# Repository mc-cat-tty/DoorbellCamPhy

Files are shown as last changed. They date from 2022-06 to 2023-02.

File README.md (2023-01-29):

# DoorbellCamPhy
## Notifier PCB
[Schematic](NotifierPcb/Exports/NotifierPcbSchematic.pdf)

[Board](NotifierPcb/Exports/NotifierPcbBoard.pdf)

<p>
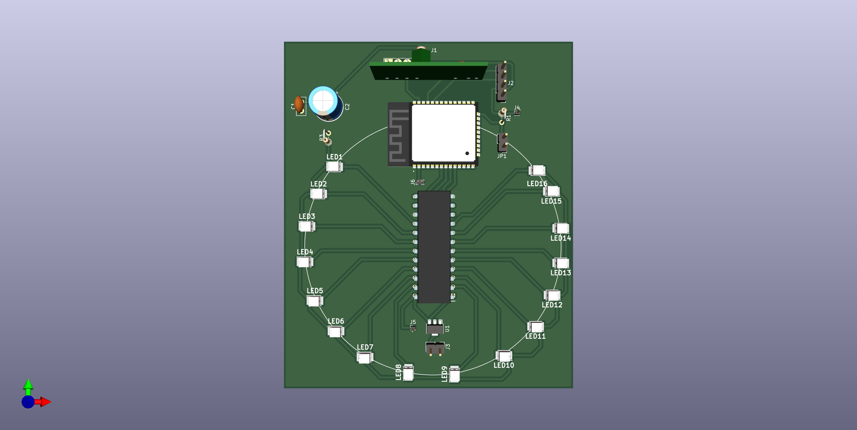
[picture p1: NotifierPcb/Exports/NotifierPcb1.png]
 
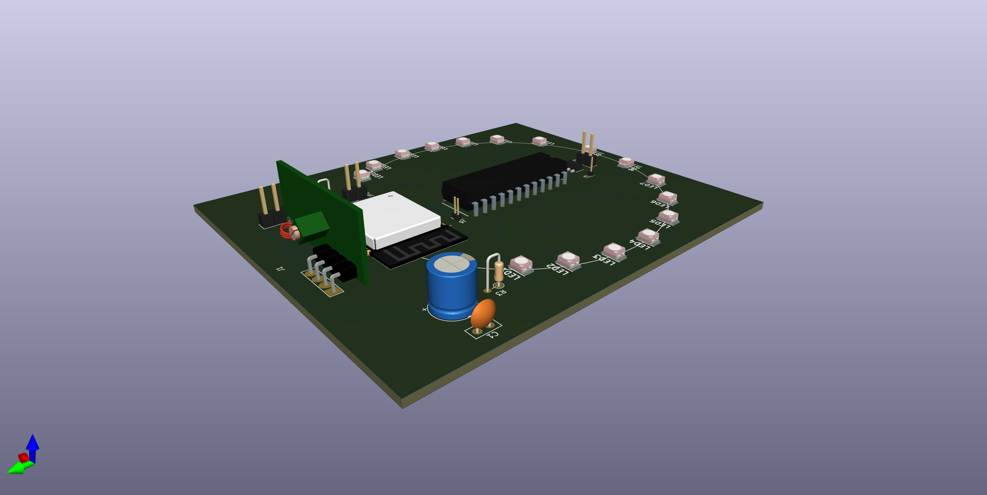
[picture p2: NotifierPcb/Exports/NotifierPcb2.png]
 
 <br>
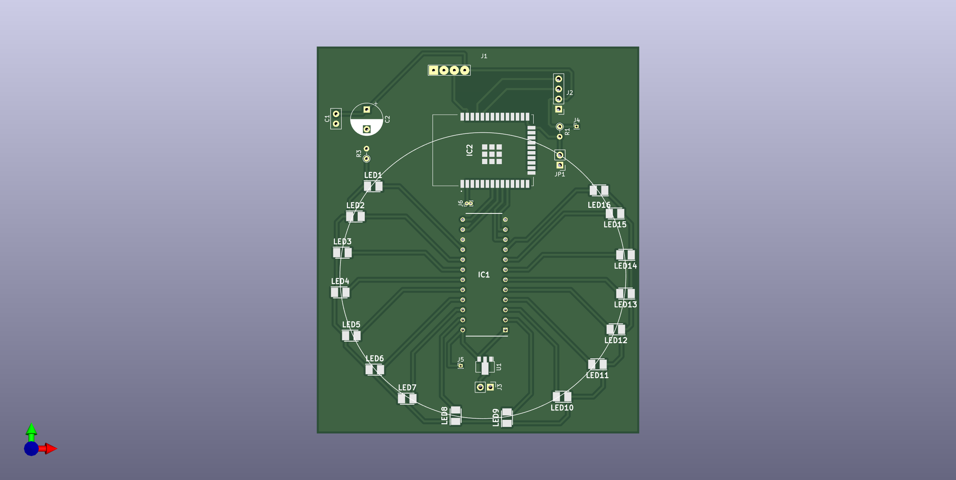
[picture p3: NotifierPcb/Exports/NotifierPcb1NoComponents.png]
 
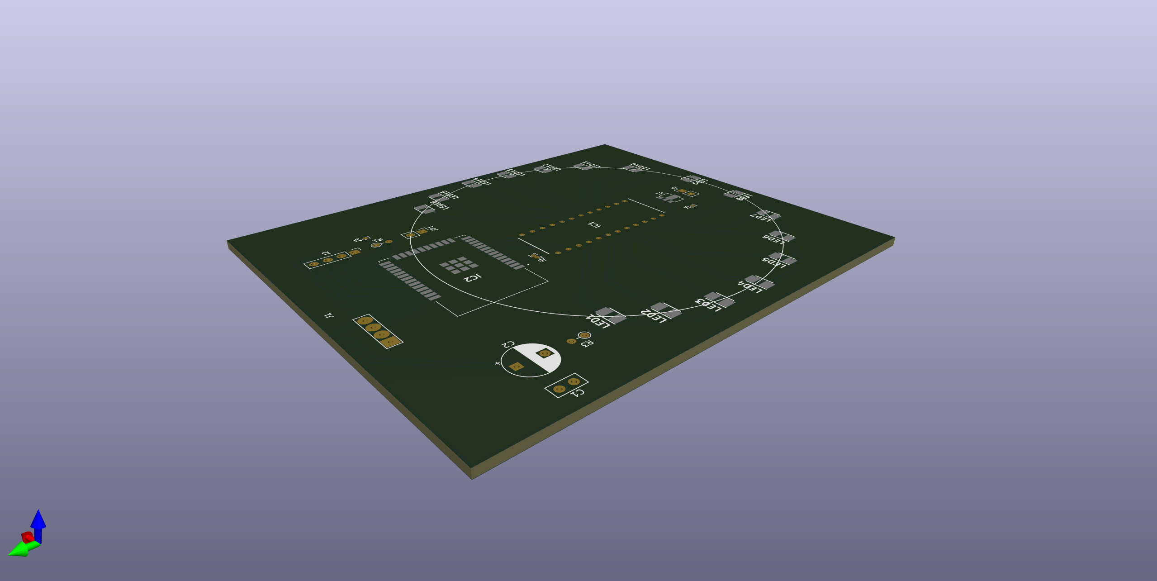
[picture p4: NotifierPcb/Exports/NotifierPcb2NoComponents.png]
 
</p>

## Notifier PCB end result


## Camera holder
[3D Model](Holder/holderv24.stl)

<p>
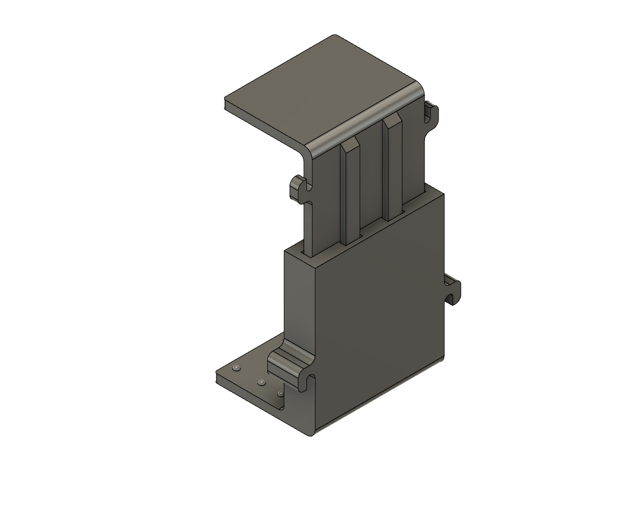
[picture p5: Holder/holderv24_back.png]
 
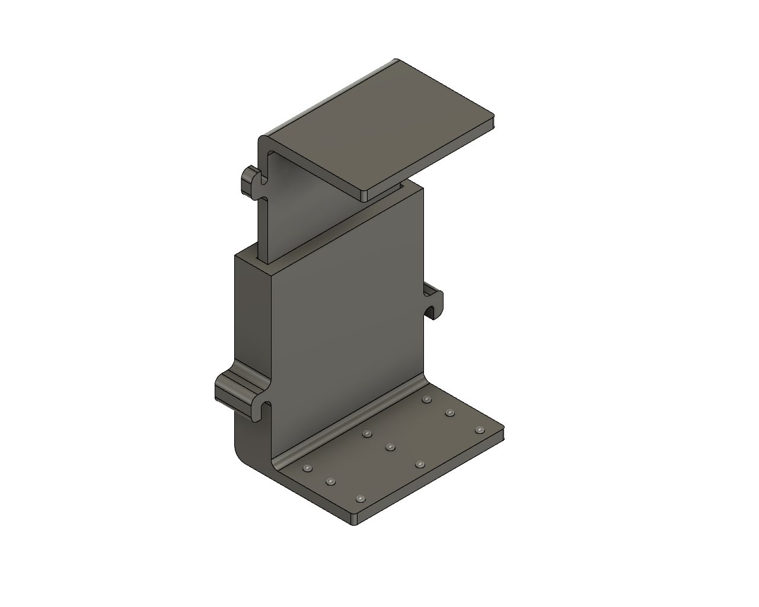
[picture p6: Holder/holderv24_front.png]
 
 <br>
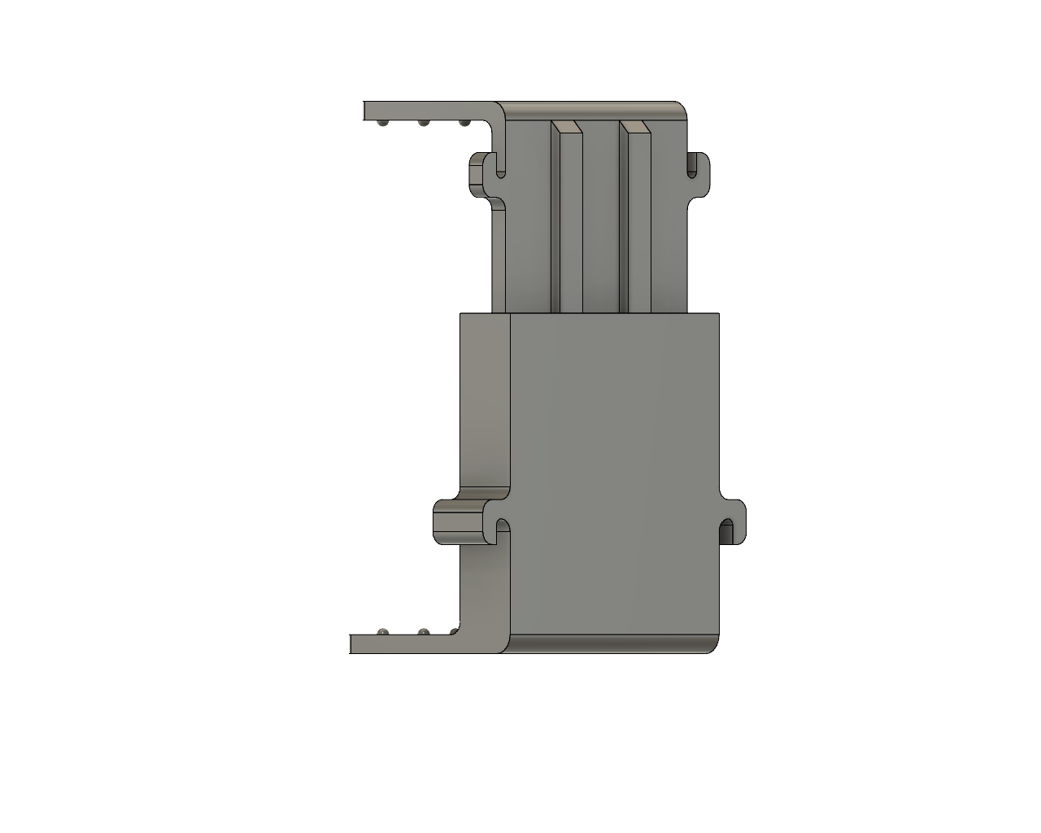
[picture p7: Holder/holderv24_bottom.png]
 
</p>

## Rasperry case base
[3D Model](Base/base.stl)

<p>
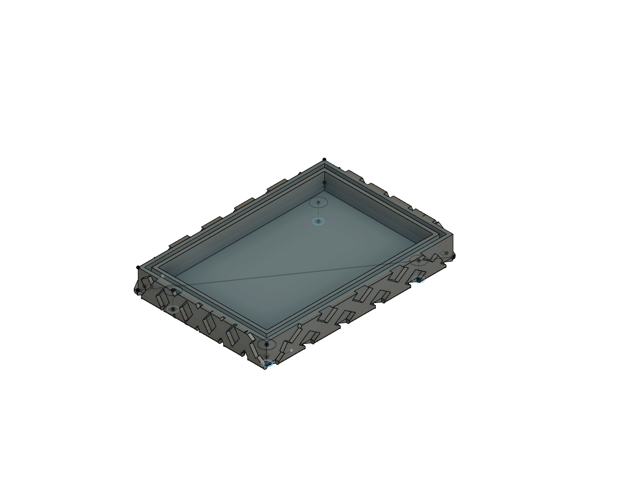
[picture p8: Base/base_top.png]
 
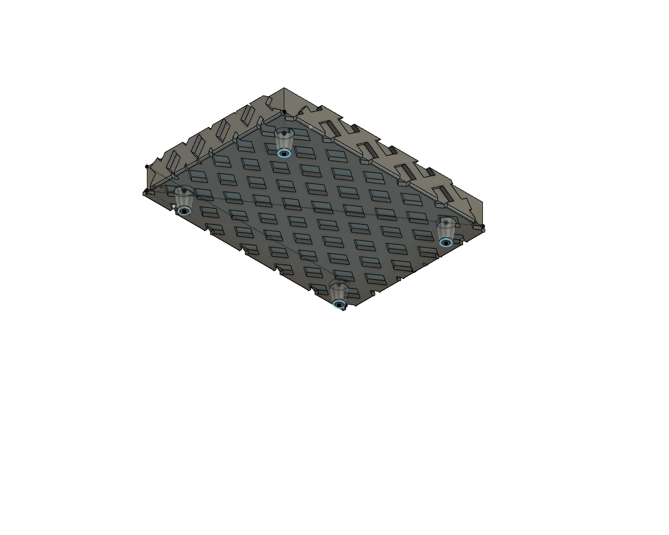
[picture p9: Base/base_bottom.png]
 
</p>

## Raspberry case columns
[3D Model](Columns/column.stl)

<p>
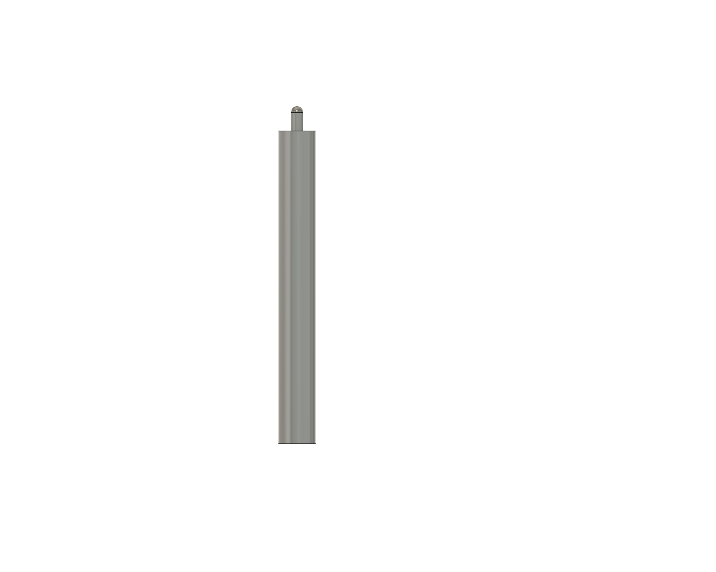
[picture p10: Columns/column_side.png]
 
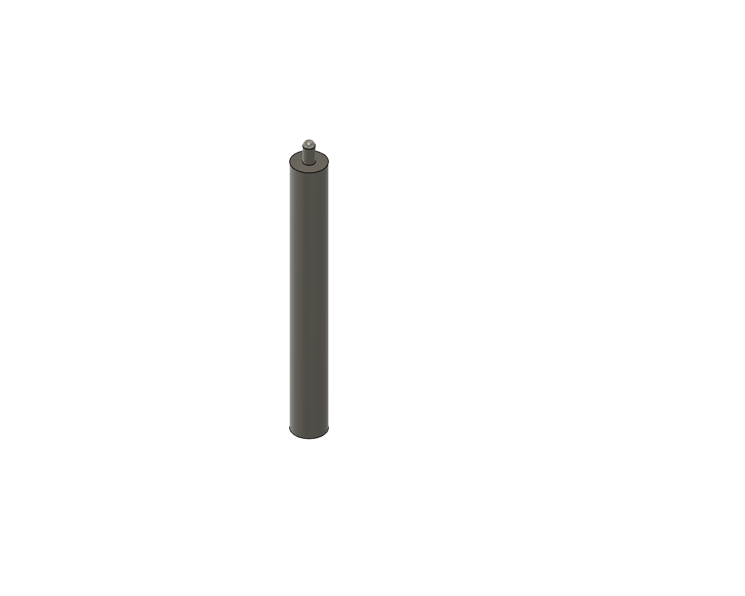
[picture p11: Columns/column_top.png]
 
 <br>
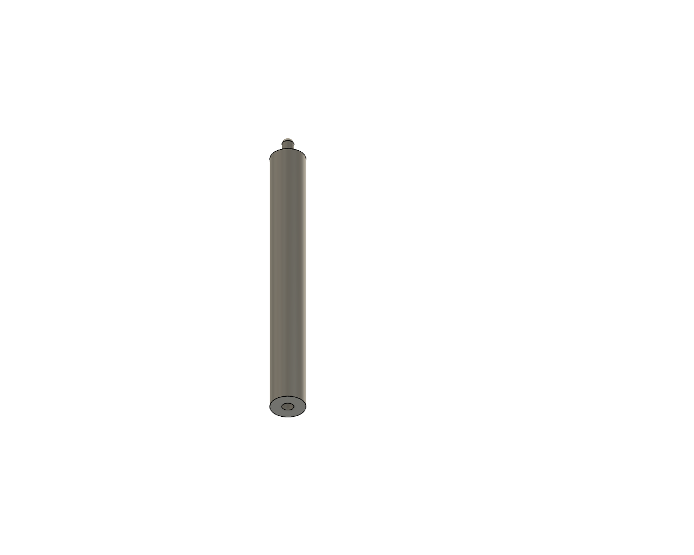
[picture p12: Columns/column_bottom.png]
 
</p>

## Raspberry case angle brackets
[3D Model](AngleBracket/angle_bracket.stl)

<p>
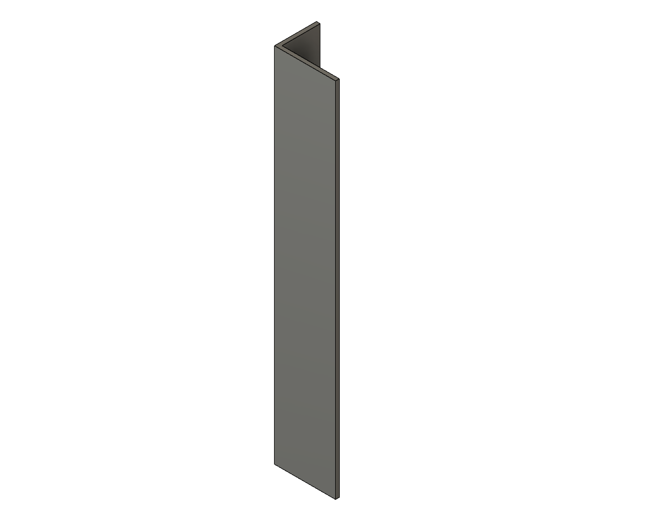
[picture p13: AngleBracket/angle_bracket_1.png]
 
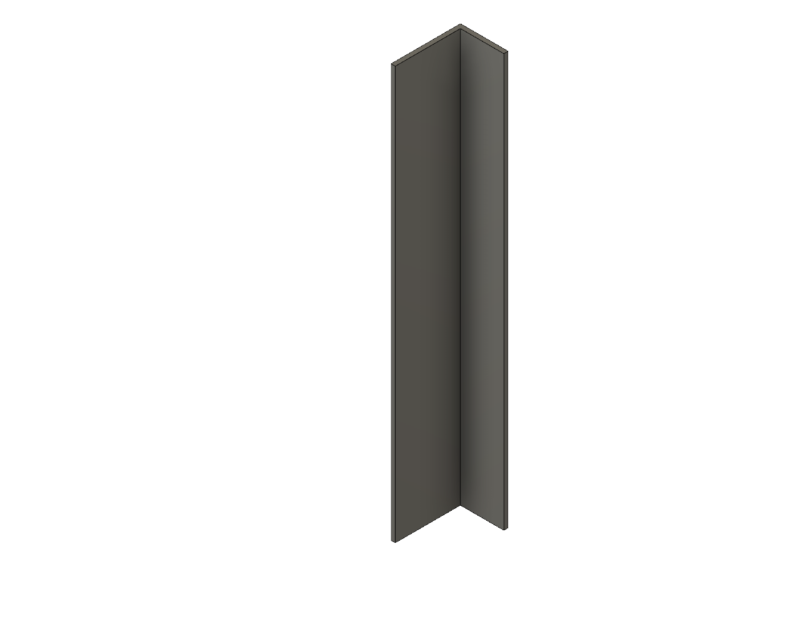
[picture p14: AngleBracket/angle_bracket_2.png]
 
</p>

## Raspberry case rooftop support
[3D Model](RooftopSupport/rooftop_support.stl)

<p>
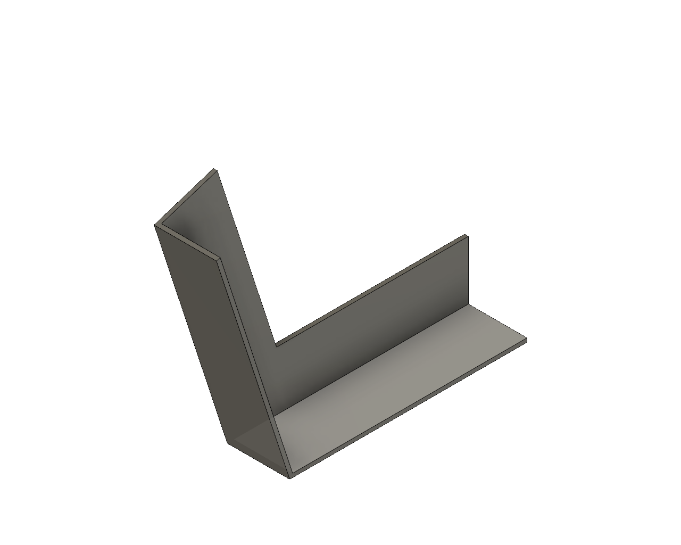
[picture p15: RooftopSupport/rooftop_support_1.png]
 
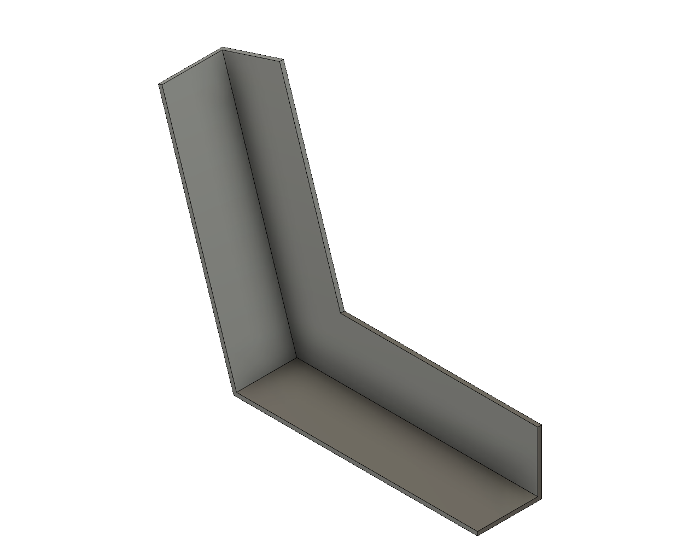
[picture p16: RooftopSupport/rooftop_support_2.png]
 
</p>

## Raspberry case IRL
<p>
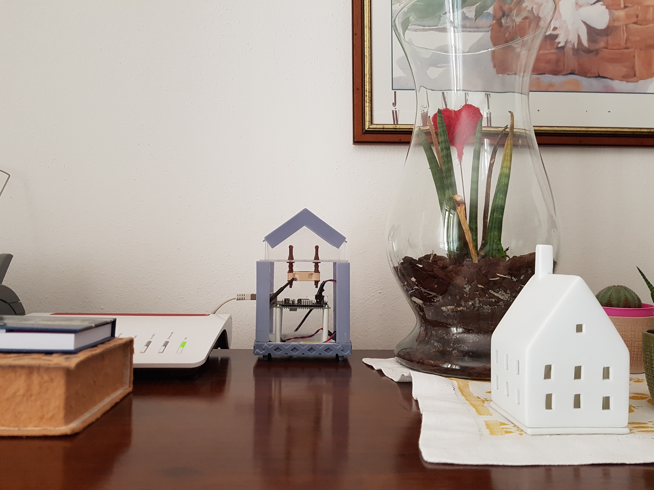
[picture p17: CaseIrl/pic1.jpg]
 
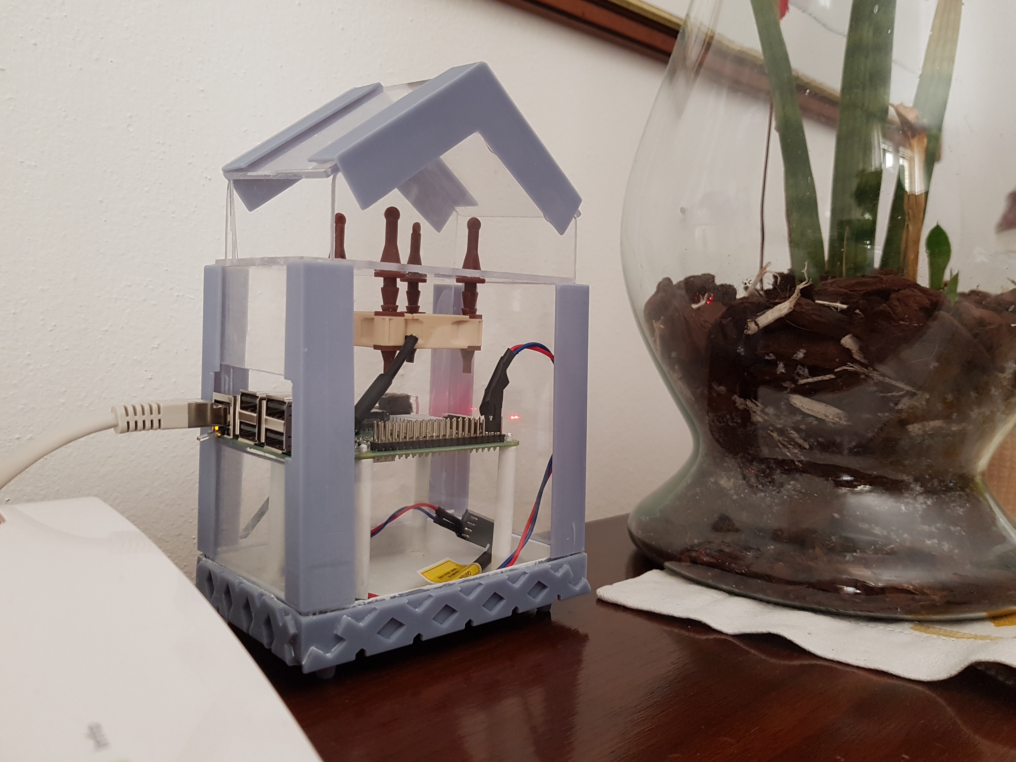
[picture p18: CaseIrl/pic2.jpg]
 
</p>

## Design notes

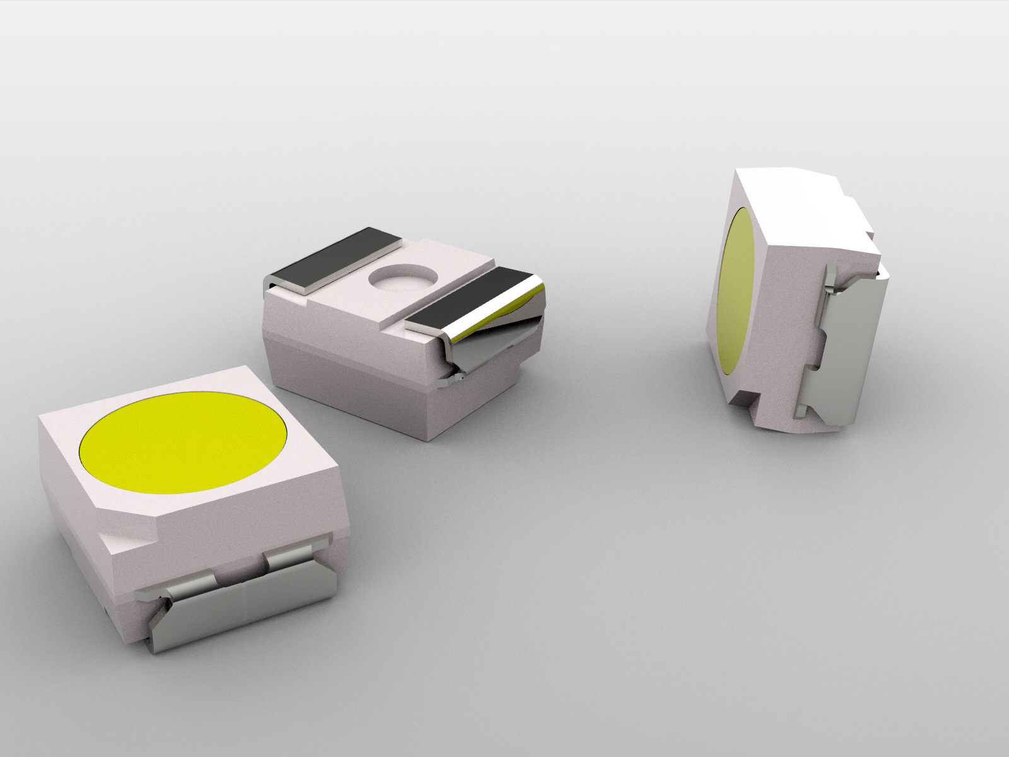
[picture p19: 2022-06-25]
NotifierPcb/LIB_AA3528QBS_D/AA3528QBS_D/3D/LED PLCC-2 SMD.jpg

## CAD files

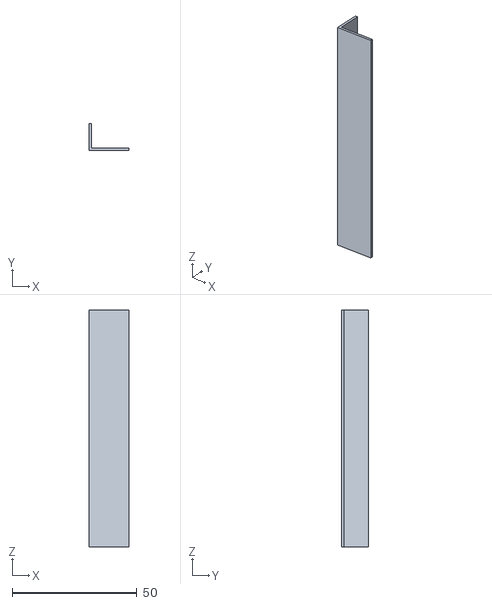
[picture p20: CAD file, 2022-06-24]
AngleBracket/angle_bracket.stl
16.0 x 11.0 x 95.0

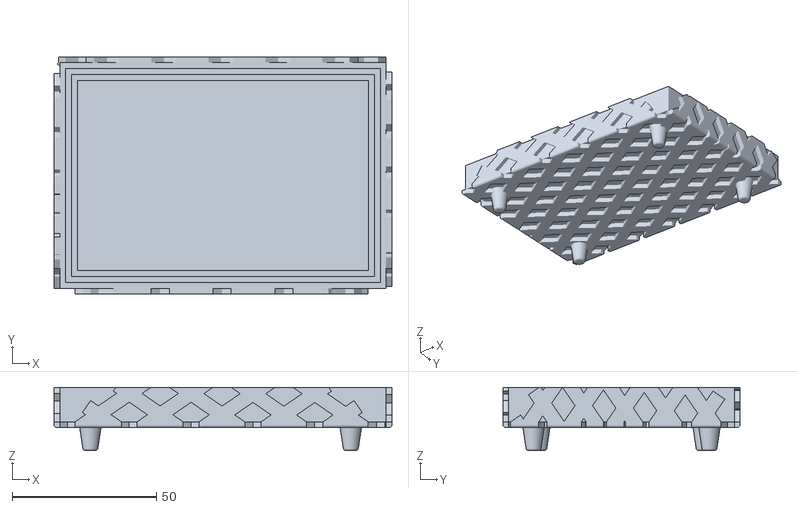
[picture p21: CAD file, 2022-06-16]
Base/base.stl
117.2 x 82.2 x 22.0

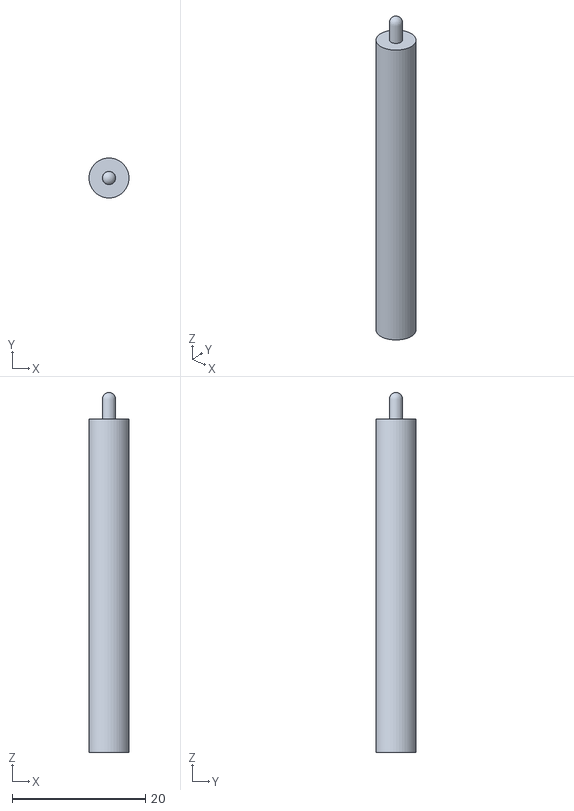
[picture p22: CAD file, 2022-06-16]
Columns/column.stl
6.00 x 5.98 x 54.0

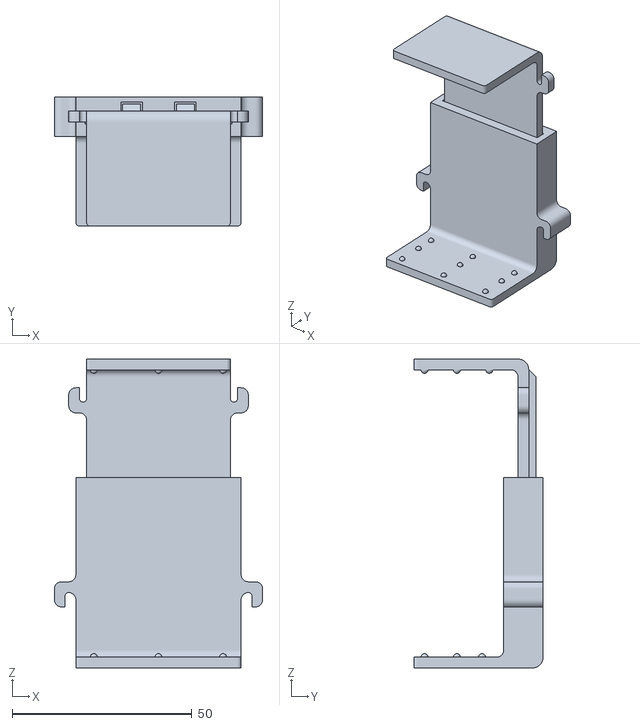
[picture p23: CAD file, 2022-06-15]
Holder/holderv24.stl
58.0 x 36.0 x 86.0

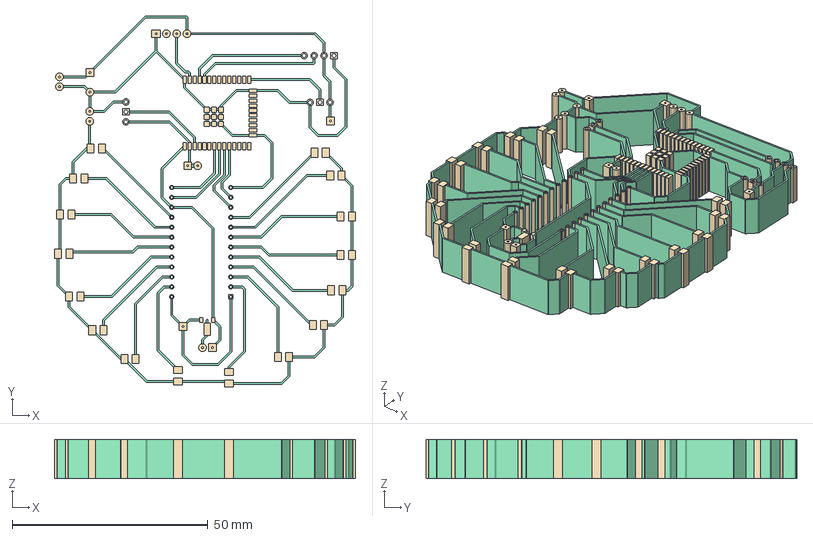
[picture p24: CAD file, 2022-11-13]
NotifierPcb/DoorbellCamPhy.FCStd
76.9 x 94.8 x 10.0 mm

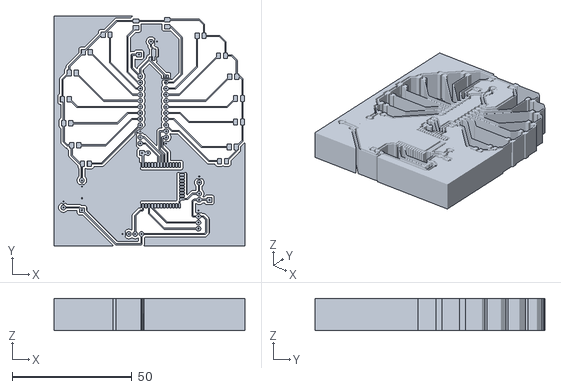
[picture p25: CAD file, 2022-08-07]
NotifierPcb/Exports/NotifierPcbExtrusionMirrored.stl
79.6 x 95.9 x 13.4

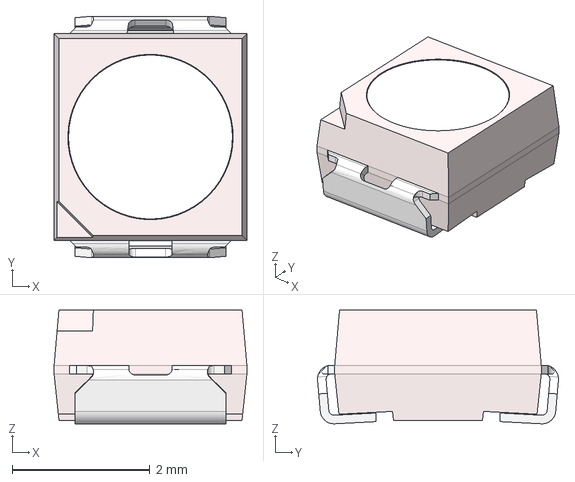
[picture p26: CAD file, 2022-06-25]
NotifierPcb/LIB_AA3528QBS_D/AA3528QBS_D/3D/LED PLCC-2.stp
2.80 x 3.50 x 1.65 mm

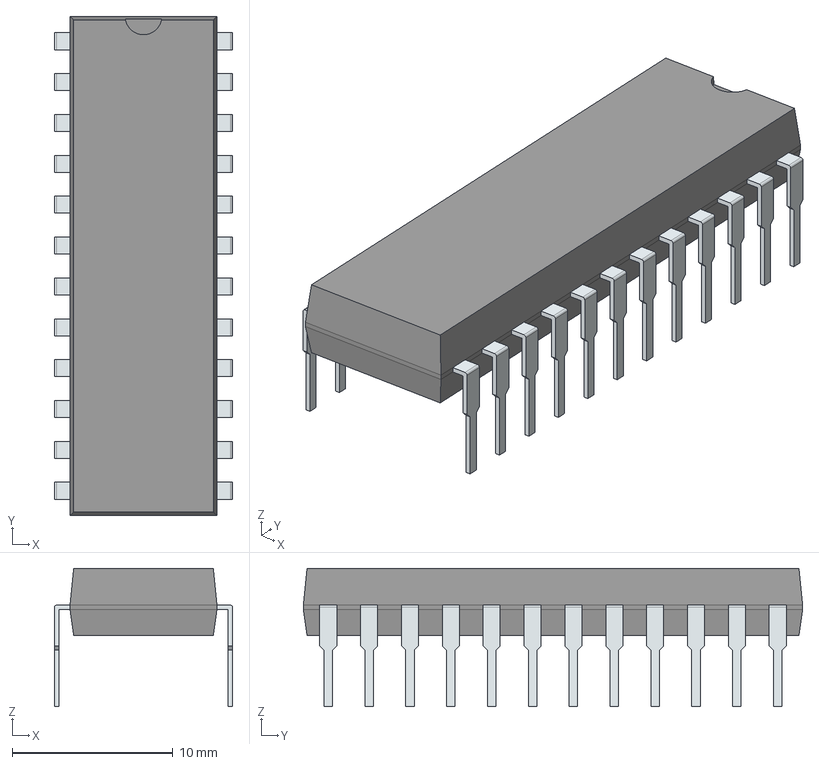
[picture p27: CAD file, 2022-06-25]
NotifierPcb/LIB_CD4067BEE4/CD4067BEE4/3D/CD4067BEE4.stp
11.1 x 31.0 x 8.58 mm
PinsArrayLR

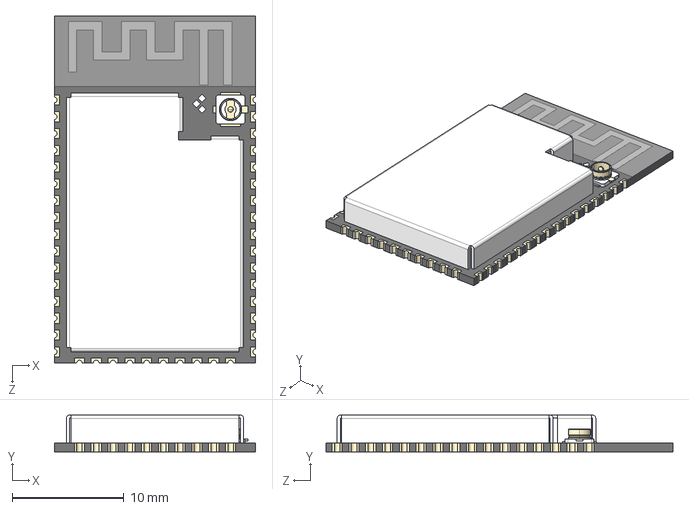
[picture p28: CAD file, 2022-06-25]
NotifierPcb/LIB_ESP32-S2-WROOM-I_M22S2H3200UH3Q0_/ESP32-S2-WROOM-I_M22S2H3200UH3Q0_/3D/ESP32-S2-WROOM-I_M22S2H3200UH3Q0_.stp
18.0 x 3.30 x 31.0 mm

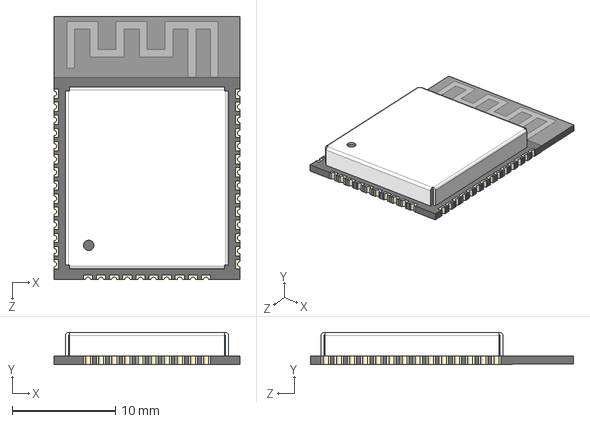
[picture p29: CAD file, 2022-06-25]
NotifierPcb/LIB_ESP32-WROOM-32E__8MB_/ESP32-WROOM-32E__8MB_/3D/ESP32-WROOM-32E__8MB_.stp
18.0 x 3.10 x 25.5 mm

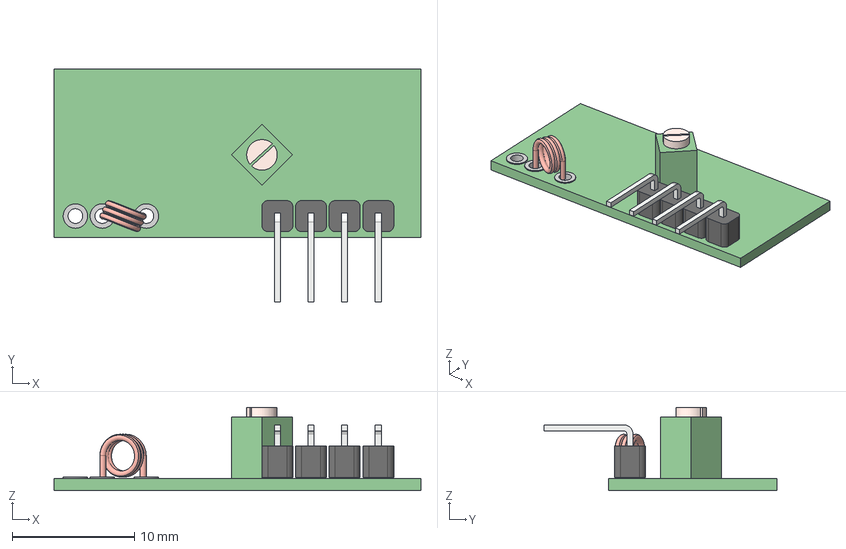
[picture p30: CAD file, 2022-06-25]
NotifierPcb/RC_433_RF_LIB/433MhzRX v4.step
30.0 x 19.0 x 6.80 mm
pcb
Pin Header Bendt x 4
small coil v1
Frequency Selector

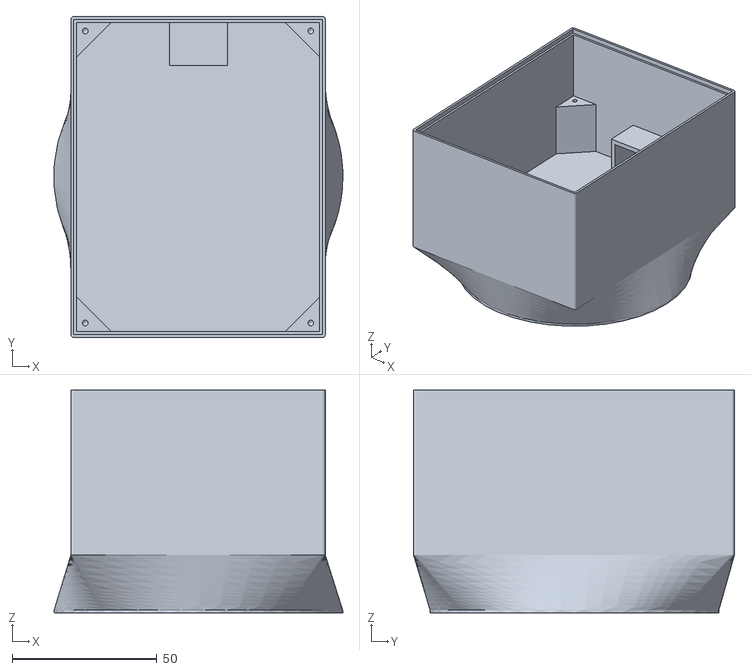
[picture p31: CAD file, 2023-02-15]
PcbEnclosure/Enclosure.obj
99.9 x 111.0 x 77.0

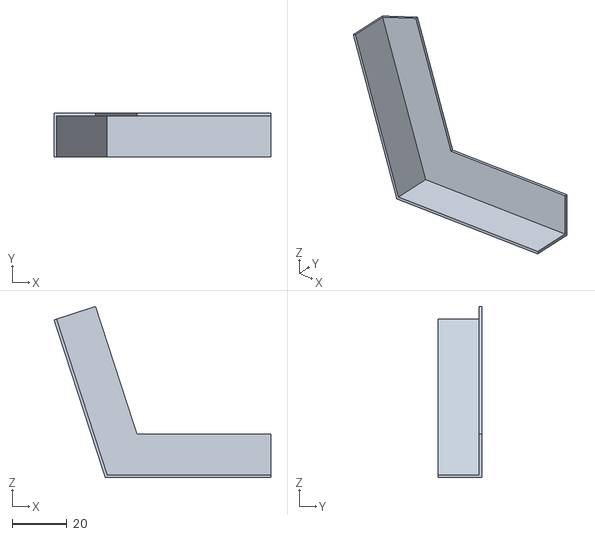
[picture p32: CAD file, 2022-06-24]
RooftopSupport/rooftop_support.stl
79.5 x 16.0 x 62.7

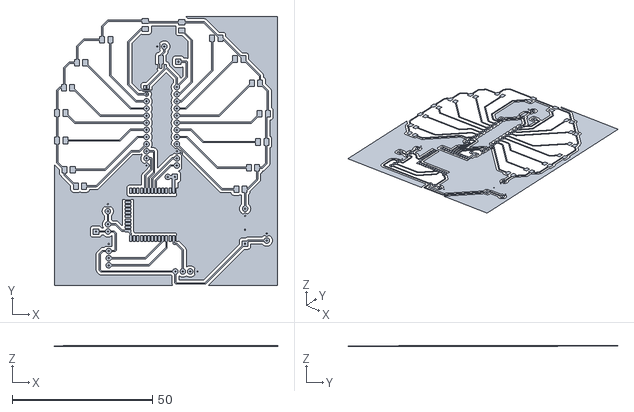
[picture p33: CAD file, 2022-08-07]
NotifierPcb/Exports/NotifierPcbFlat.stl
79.6 x 95.9 x 1.86e-05

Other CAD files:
NotifierPcb/Exports/NotifierPcbExtrusion.stl
NotifierPcb/Exports/NotifierPcbFlatMirrored.stl
AngleBracket/angle_bracket.f3d
AngleBracket/angle_bracket.obj
Base/base.f3d
Base/base.obj
Columns/column.f3d
Columns/column.obj
Holder/holderv24.f3d
Holder/holderv24.obj
NotifierPcb/LIB_AA3528QBS_D/AA3528QBS_D/Allegro/ledm3528x210n.psm
NotifierPcb/LIB_AA3528QBS_D/AA3528QBS_D/DEHDL/aa3528qbs_d/chips/chips.prt
NotifierPcb/LIB_CD4067BEE4/CD4067BEE4/3D/CD4067BEE4.stl
NotifierPcb/LIB_CD4067BEE4/CD4067BEE4/Allegro/dip1080w53p254l3104h508q24n.psm
NotifierPcb/LIB_CD4067BEE4/CD4067BEE4/DEHDL/cd4067bee4/chips/chips.prt
NotifierPcb/LIB_ESP32-S2-WROOM-I_M22S2H3200UH3Q0_/ESP32-S2-WROOM-I_M22S2H3200UH3Q0_/Allegro/esp32s2wroomim22s2h3200uh3q0.psm
NotifierPcb/LIB_ESP32-S2-WROOM-I_M22S2H3200UH3Q0_/ESP32-S2-WROOM-I_M22S2H3200UH3Q0_/DEHDL/esp32_s2_wroom_i_m22s2h3200uh3q0_/chips/chips.prt
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

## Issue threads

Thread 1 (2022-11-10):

CD4067 fingerprint is too small

mc-cat-tty, 2022-11-10:

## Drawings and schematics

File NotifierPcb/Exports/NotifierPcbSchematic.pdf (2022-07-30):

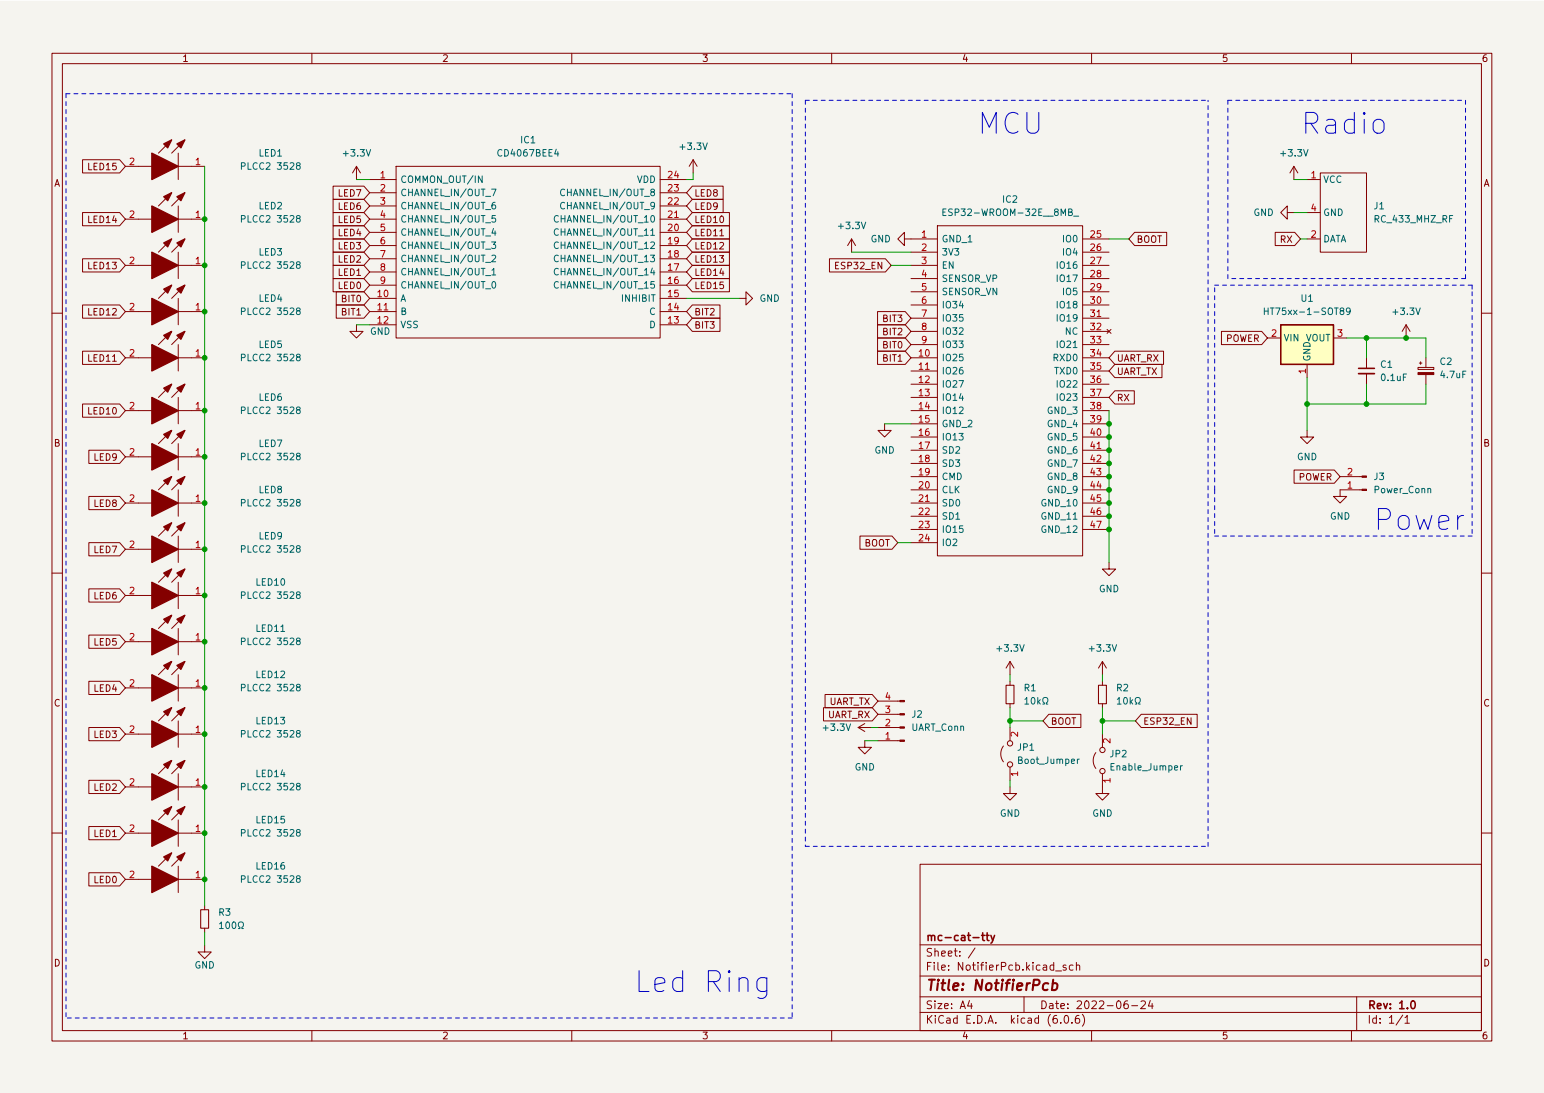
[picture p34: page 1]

File: NotifierPcb.kicad_sch Sheet: / mc-cat-tty

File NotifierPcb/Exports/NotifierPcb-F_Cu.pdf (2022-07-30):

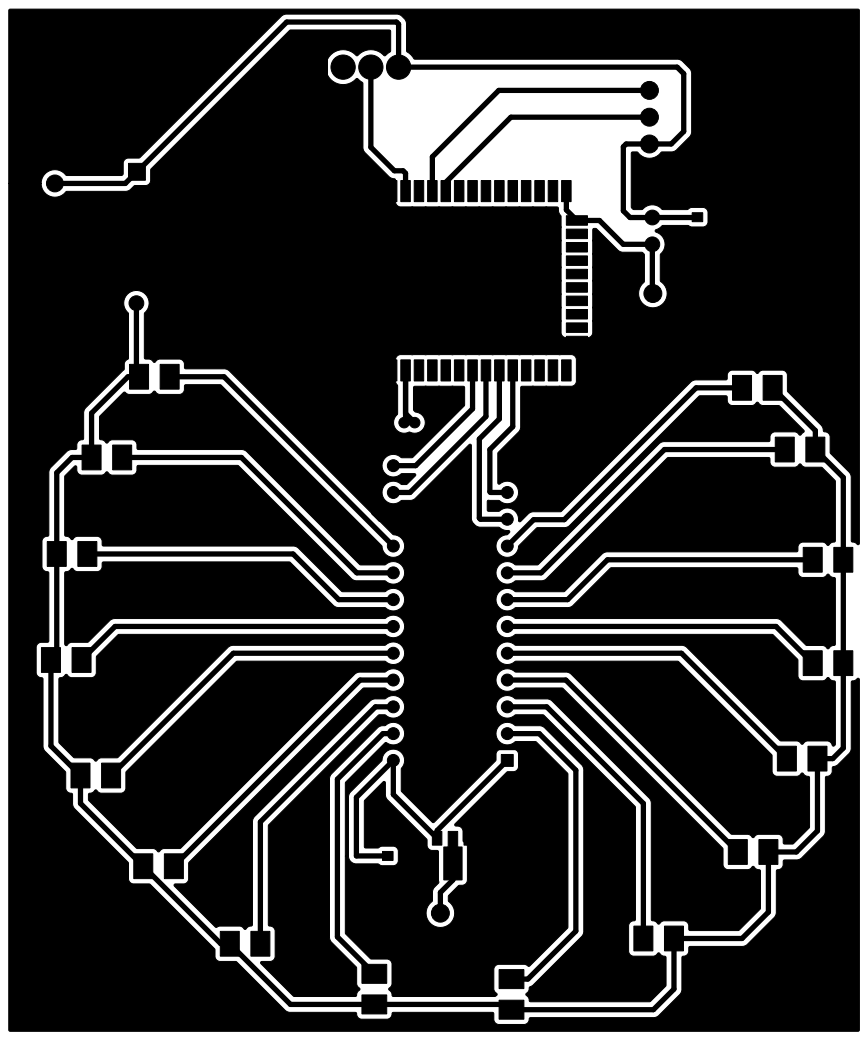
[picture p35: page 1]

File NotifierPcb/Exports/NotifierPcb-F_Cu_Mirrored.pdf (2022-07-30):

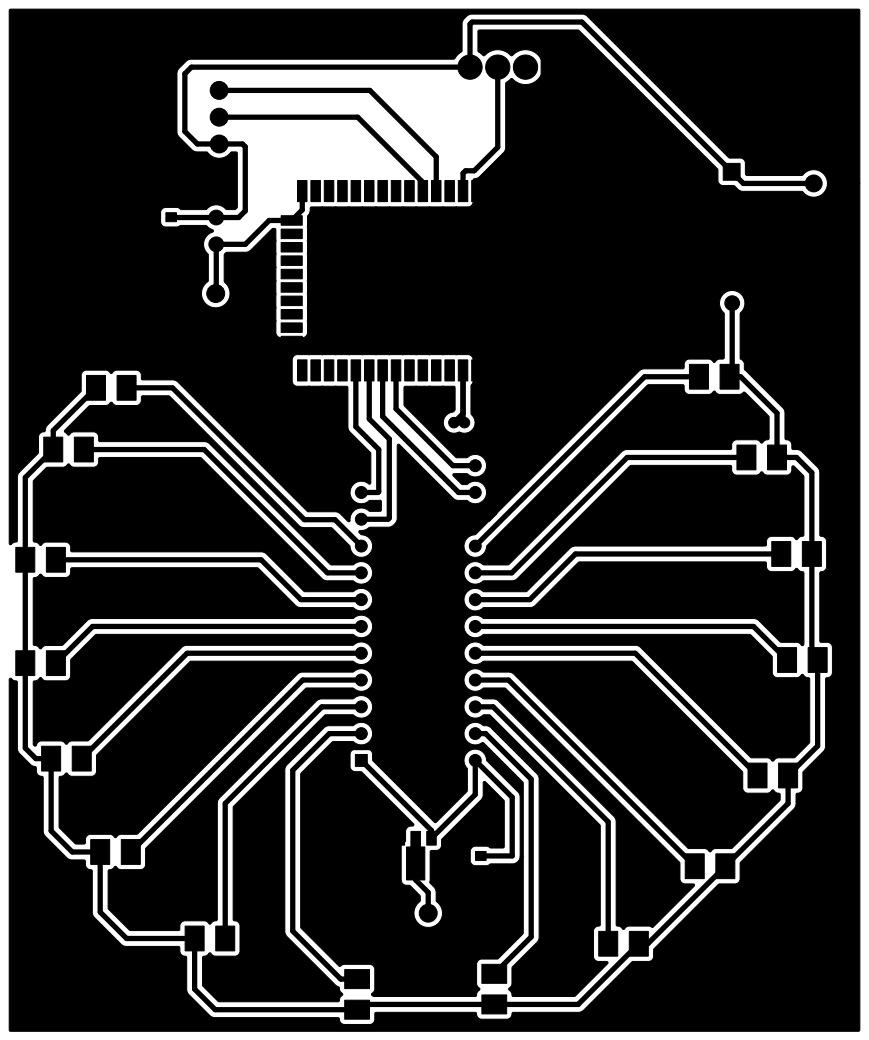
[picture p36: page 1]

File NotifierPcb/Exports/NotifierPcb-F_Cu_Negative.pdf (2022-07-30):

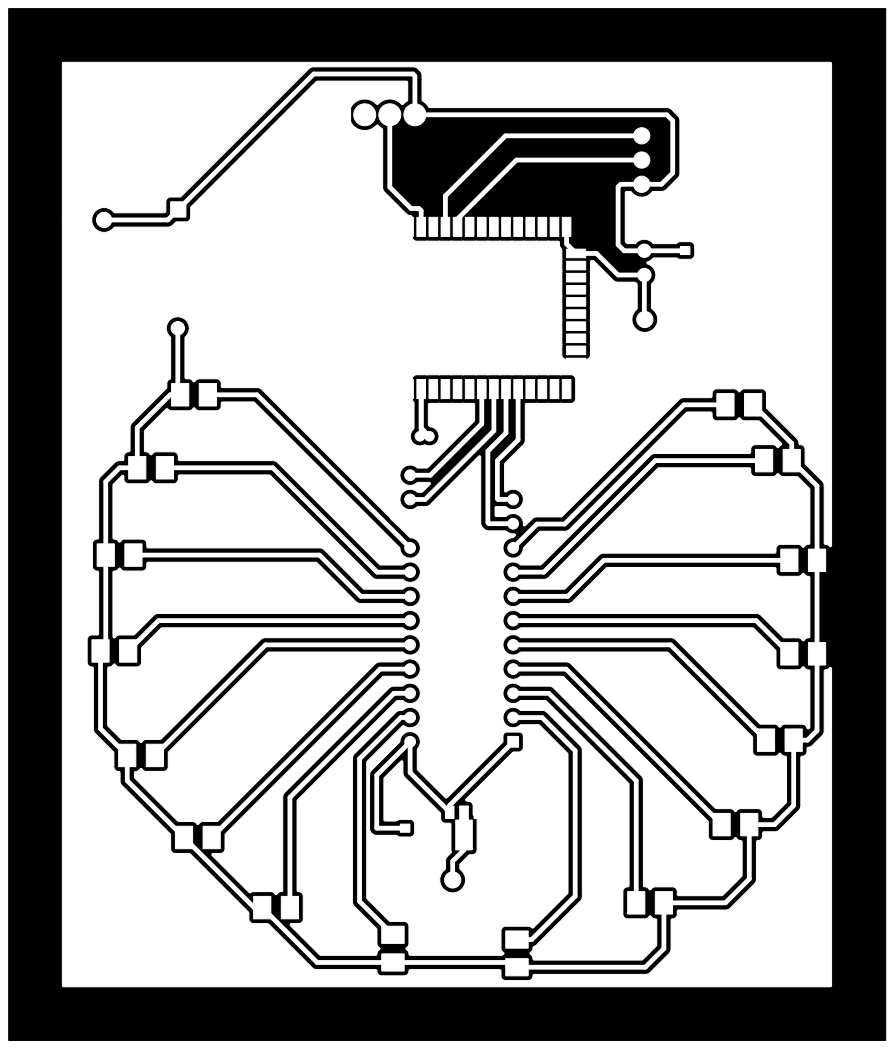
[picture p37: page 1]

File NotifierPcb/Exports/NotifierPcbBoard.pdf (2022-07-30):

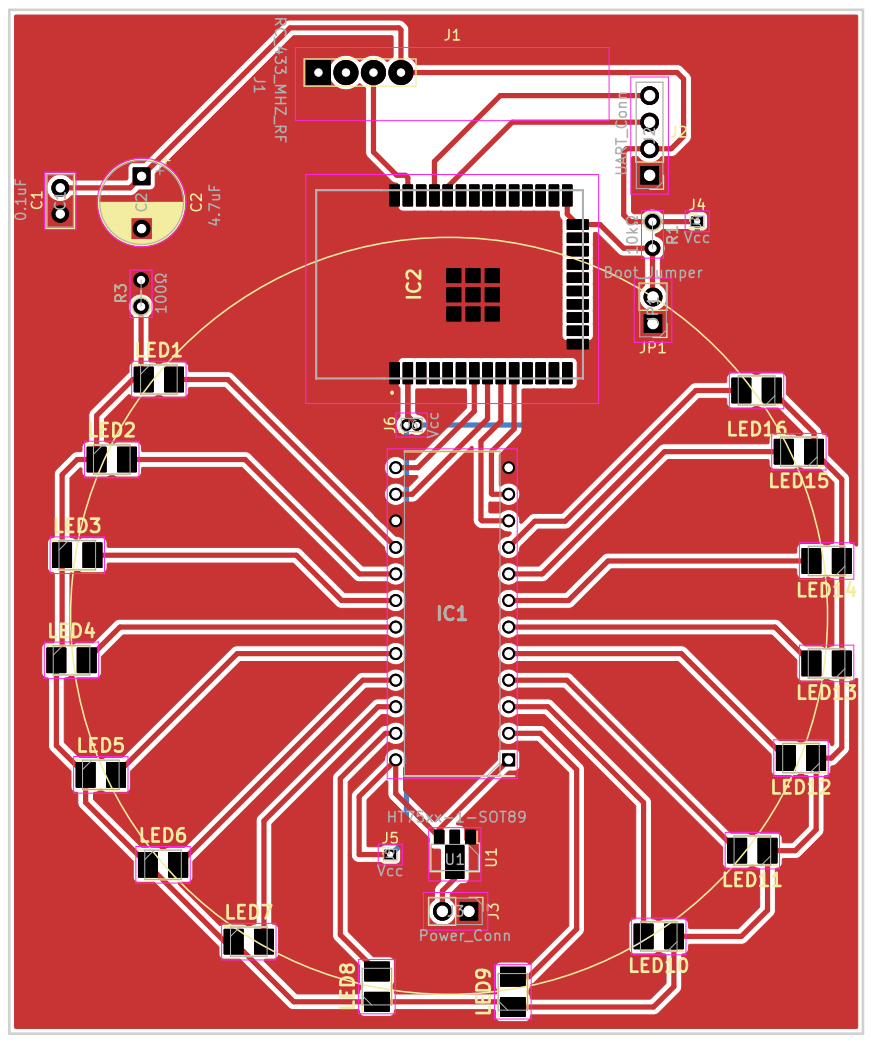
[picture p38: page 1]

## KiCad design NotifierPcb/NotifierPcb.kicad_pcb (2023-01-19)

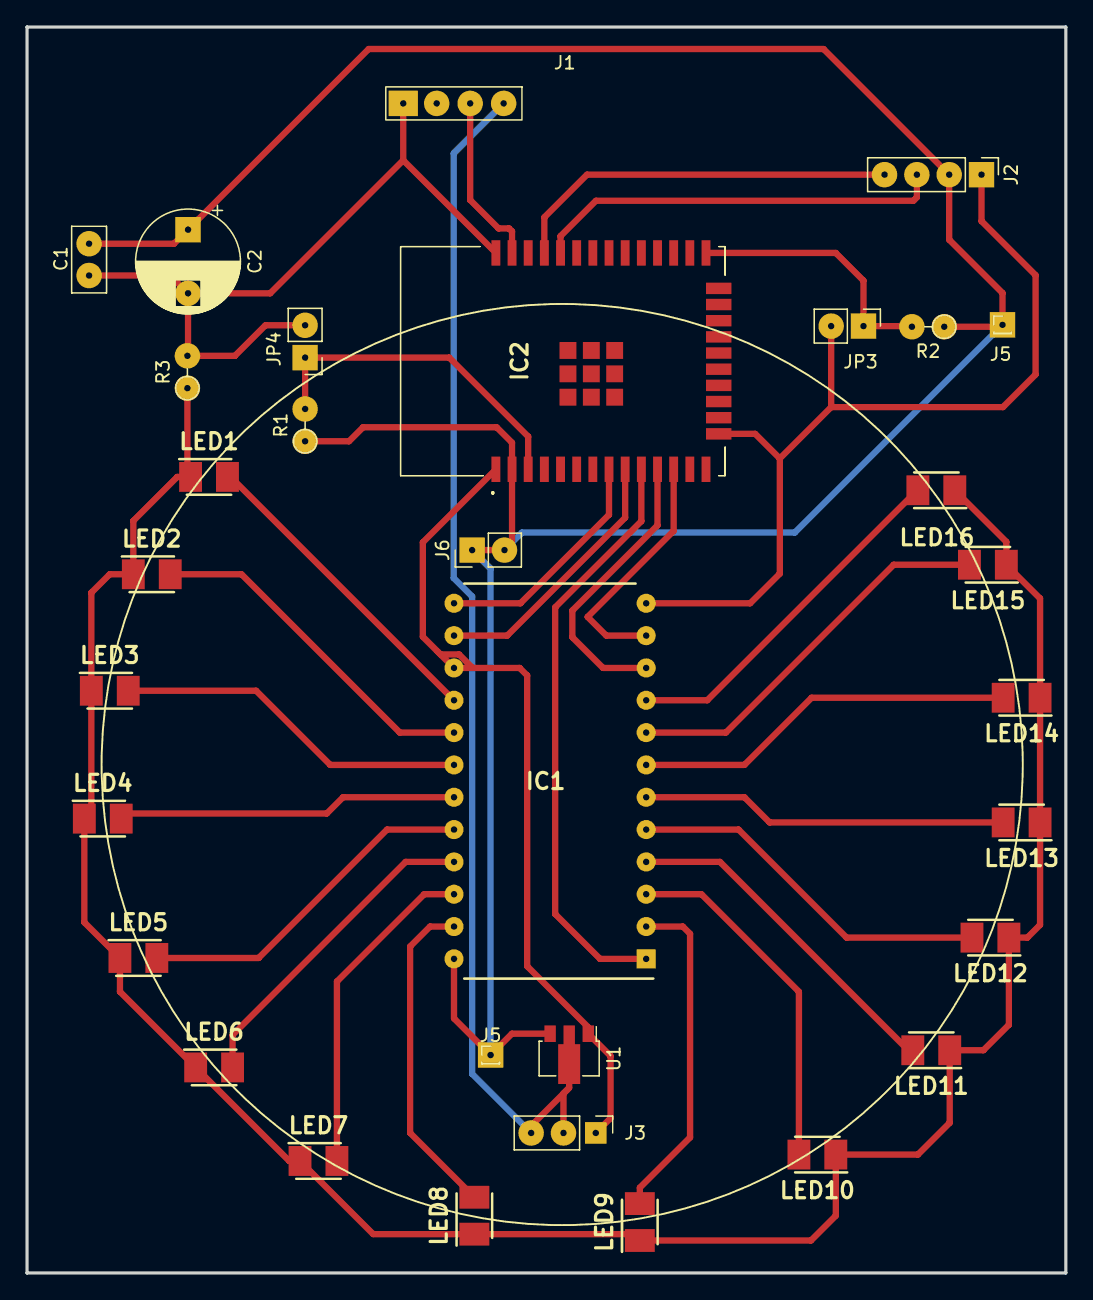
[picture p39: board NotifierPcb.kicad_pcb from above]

Board: 2 copper layers, 81.6 x 97.9 mm, 32 parts (0 on the bottom side), 30 nets.

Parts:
C1: 0.1uF; C_Disc_D5.0mm_W2.5mm_P2.50mm
C2: 4.7uF; CP_Radial_D8.0mm_P5.00mm
IC1: CD4067BEE4; DIP1080W53P254L3104H508Q24N
IC2: ESP32-WROOM-32E__8MB_; ESP32WROOM32E8MB
J1: RC_433_MHZ_RF; RC_433_RX
J2: UART_Conn; PinHeader_1x04_P2.54mm_Vertical
J3: Power; PinHeader_1x03_P2.54mm_Vertical
J5, J5#2: Vcc; PinHeader_1x01_P1.00mm_Vertical
J6: Vcc; PinHeader_1x02_P2.54mm_Vertical
JP3: Boot_Jumper_Download; PinHeader_1x02_P2.54mm_Vertical
JP4: Enable_Jumper; PinHeader_1x02_P2.54mm_Vertical
LED1, LED2, LED3, LED4, LED5, LED6, LED7, LED8, LED9, LED10, LED11, LED12, LED13, LED14, LED15, LED16: PLCC2 3528; LEDM3528X210N
R1, R2: 10kΩ; R_Axial_DIN0204_L3.6mm_D1.6mm_P2.54mm_Vertical
R3: 100Ω; R_Axial_DIN0204_L3.6mm_D1.6mm_P2.54mm_Vertical
U1: HT75xx-1-SOT89; SOT-89-3

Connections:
+3.3V: C1.1, C2.1, IC1.24 (VDD), IC2.2 (3V3), J2.2, J5.1, J5#2.1, J6.1, J6.2, R1.1, U1.3 (VOUT)
+5V: J1.1 (VCC), J3.2, J3.3, U1.2 (VIN)
BIT0: IC1.10 (A), IC2.11 (IO26)
BIT1: IC1.11 (B), IC2.12 (IO27)
BIT2: IC1.14 (C), IC2.9 (IO33)
BIT3: IC1.13 (D), IC2.8 (IO32)
BOOT: IC2.25 (IO0), JP3.1 (A), R2.2
DEMUX_IN: IC1.1 (COMMON_OUT/IN), IC2.10 (IO25)
ESP32_EN: IC2.3 (EN), JP4.1 (A)
GND: C1.2, C2.2, IC1.12 (VSS), IC1.15 (INHIBIT), IC2.1 (GND_1), IC2.15 (GND_2), IC2.38 (GND_3), IC2.39 (GND_4), IC2.40 (GND_5), IC2.41 (GND_6), IC2.42 (GND_7), IC2.43 (GND_8), IC2.44 (GND_9), IC2.45 (GND_10), IC2.46 (GND_11), IC2.47 (GND_12), J1.4 (GND), J2.1, J3.1, JP3.2 (B), JP4.2 (B), R3.2, U1.1 (GND)
LED0: IC1.9 (CHANNEL_IN/OUT_0), LED16.2
LED1: IC1.8 (CHANNEL_IN/OUT_1), LED15.2
LED2: IC1.7 (CHANNEL_IN/OUT_2), LED14.2
LED3: IC1.6 (CHANNEL_IN/OUT_3), LED13.2
LED4: IC1.5 (CHANNEL_IN/OUT_4), LED12.2
LED5: IC1.4 (CHANNEL_IN/OUT_5), LED11.2
LED6: IC1.3 (CHANNEL_IN/OUT_6), LED10.2
LED7: IC1.2 (CHANNEL_IN/OUT_7), LED9.2
LED8: IC1.23 (CHANNEL_IN/OUT_8), LED8.2
LED9: IC1.22 (CHANNEL_IN/OUT_9), LED7.2
LED10: IC1.21 (CHANNEL_IN/OUT_10), LED6.2
LED11: IC1.20 (CHANNEL_IN/OUT_11), LED5.2
LED12: IC1.19 (CHANNEL_IN/OUT_12), LED4.2
LED13: IC1.18 (CHANNEL_IN/OUT_13), LED3.2
LED14: IC1.17 (CHANNEL_IN/OUT_14), LED2.2
LED15: IC1.16 (CHANNEL_IN/OUT_15), LED1.2
unnamed: LED1.1, LED2.1, LED3.1, LED4.1, LED5.1, LED6.1, LED7.1, LED8.1, LED9.1, LED10.1, LED11.1, LED12.1, LED13.1, LED14.1, LED15.1, LED16.1, R3.1
RX: IC2.37 (IO23), J1.2 (DATA)
UART_RX: IC2.34 (RXD0), J2.3
UART_TX: IC2.35 (TXD0), J2.4

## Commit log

2022-06-16 create column 3d model
    [column.f3d, column.obj, column.stl]
2022-06-16 create base 3d model
    [base.f3d, base.obj, base.stl]
2022-06-24 add rooftop support and angular brackets
    [angle_bracket.f3d, angle_bracket.obj, angle_bracket.stl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]
2022-06-25 kickstart pcb design
    [433MhzRX v4.step, CD4067BEE4.stl, CD4067BEE4.stp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]
2022-07-09 add case irl
2022-07-29 done schematic
    [NotifierPcb.kicad_sch]
2022-07-29 label table areas
    [NotifierPcb.kicad_sch]
2022-07-29 add annotations
    [NotifierPcb.kicad_sch]
2022-07-29 wokring on pcb
    [NotifierPcb.kicad_pcb, NotifierPcb.kicad_sch]
2022-07-29 plot pcb
2022-07-30 arrange leds in circle, add missing components
    [NotifierPcb.kicad_pcb, NotifierPcb.kicad_sch]
2022-07-30 done pcb beta version
    [NotifierPcb.kicad_pcb, NotifierPcb.kicad_sch]
2022-07-30 add keepout zone, ground plane£
    [NotifierPcb.kicad_pcb]
2022-07-30 move external margin to Edge.Cuts
    [NotifierPcb.kicad_pcb]
2022-07-30 exports pcb sheets
    [NotifierPcb.kicad_pcb]
2022-07-30 plot production files
    [NotifierPcb.kicad_pcb]
2022-08-07 make pads bigger
    [NotifierPcb.kicad_pcb]
2022-08-07 add extrusions
    [NotifierPcbExtrusion.stl, NotifierPcbExtrusionMirrored.stl, NotifierPcbFlat.stl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]
2022-11-12 fixing strapping pins for download mode
    [NotifierPcb.kicad_sch]
2022-11-13 new configuratio for boot pins selection
    [NotifierPcb.kicad_pcb, NotifierPcb.kicad_sch]
2022-11-13 enlarge cd4067 pads
    [DoorbellCamPhy.FCStd, NotifierPcb.kicad_pcb]
2022-11-13 add gnd for cd4067
    [NotifierPcb.kicad_pcb]
2022-11-14 reroute GND for headers
    [NotifierPcb.kicad_pcb, NotifierPcb.kicad_sch]
2022-11-14 trying to fix
    [NotifierPcb.kicad_pcb]
2022-11-15 enlarge pads
    [NotifierPcb.kicad_pcb]
2022-11-24 remove unused flag selectors (default pin state)
    [NotifierPcb.kicad_pcb, NotifierPcb.kicad_sch]
2022-11-24 FIX: using only-input pin
    [NotifierPcb.kicad_pcb, NotifierPcb.kicad_sch]
2022-11-28 add pullup resistor for strapping pins
    [NotifierPcb.kicad_pcb, NotifierPcb.kicad_sch]
2022-11-29 control demux input
    [NotifierPcb.kicad_pcb, NotifierPcb.kicad_sch]
2023-01-19 power rf receiver with 5V
    [NotifierPcb.kicad_pcb, NotifierPcb.kicad_sch]
2023-02-15 Add PcbEnclosure via upload
    [Enclosure.obj, PcbEnclosure.f3d]
